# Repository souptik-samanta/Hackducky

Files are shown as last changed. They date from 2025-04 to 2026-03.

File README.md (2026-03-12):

# HackDucky - A penetration testing tool.

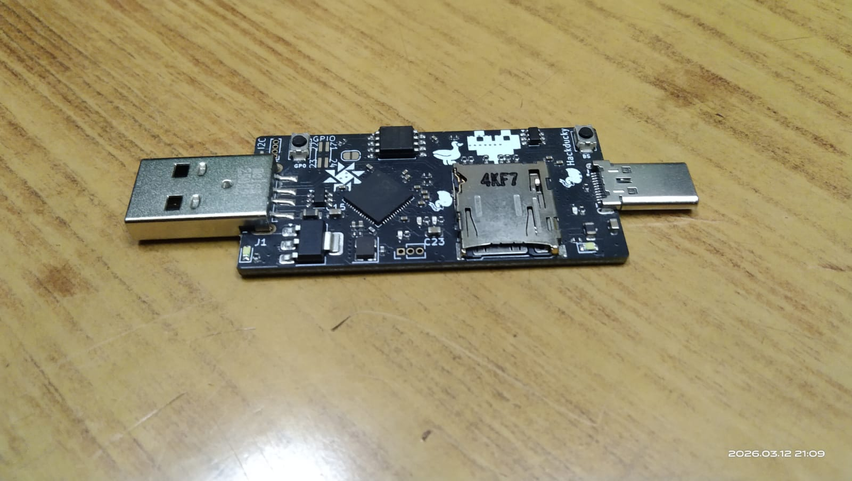
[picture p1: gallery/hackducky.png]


## What is HackDucky
HackDucky is a compact USB automation and security testing device designed in a small portable form factor. It is inspired by keystroke-injection tools and can emulate a USB keyboard to execute scripted commands automatically when plugged into a computer.The device is powered by a rp2040 and supports payload scripting, making it useful for automation, demonstrations, and authorized penetration testing.
Below is the render of the HackDucky board.
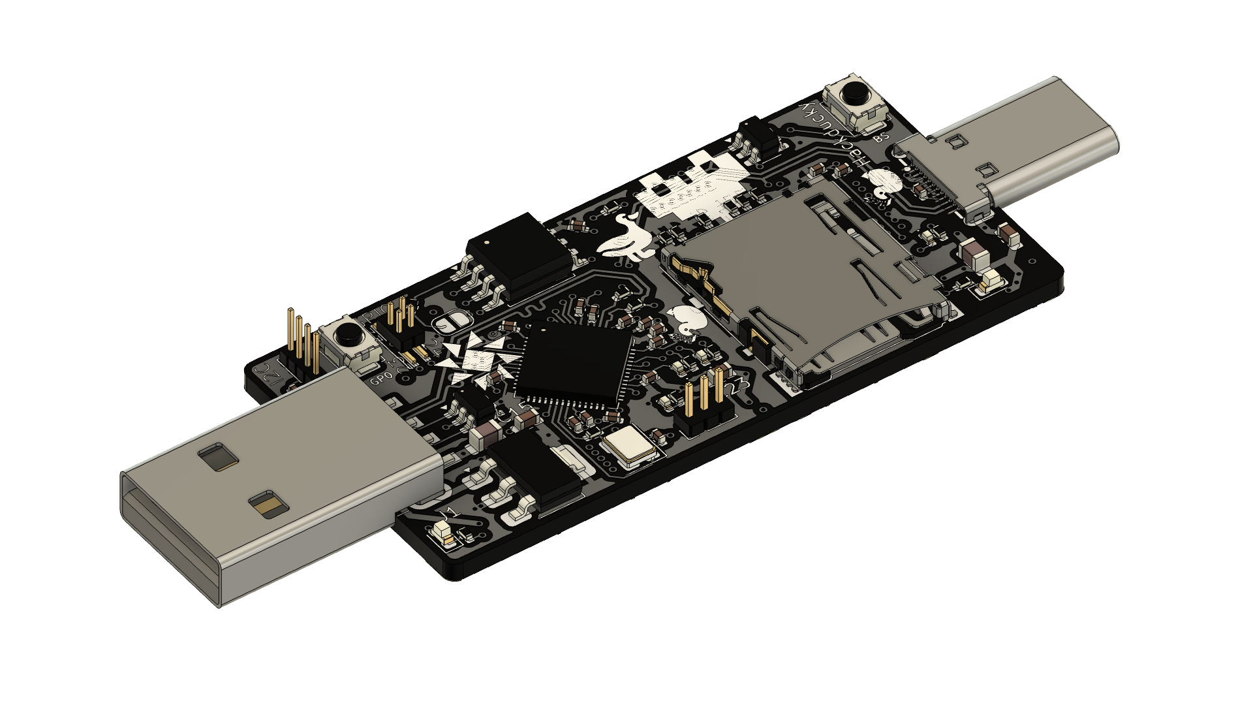
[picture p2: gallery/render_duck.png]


## Why HackDucky
Most devices designed for USB automation or security testing are either expensive, closed-source, or difficult for beginners to modify. We wanted to build something compact, affordable, and easy to experiment with while still being powerful enough for real projects. HackDucky aims to provide a small, portable platform for USB automation, inspired by devices used in security research such as USB Rubber Ducky and other BadUSB-style tools.

Our board is powered by the reliable Raspberry Pi RP2040 microcontroller and includes 16 MB of flash storage, giving plenty of room for scripts and firmware. It also features an SD card slot, allowing users to store and switch between multiple payloads or automation scripts easily. This makes the device flexible for experimentation, demos, and authorized security testing.

HackDucky is designed for a wide range of users. Students can explore how USB HID devices work and learn about hardware security concepts. Makers can use it as a programmable USB automation tool for repetitive tasks. Security enthusiasts can experiment with BadUSB-style techniques in controlled environments, while developers can modify the firmware and hardware to create their own custom tools.

# Features

- RP2040 Microcontroller – Dual-core Arm Cortex-M0+ running at 133 MHz
- 16 MB Flash Storage – Store firmware and large script libraries
- USB-A + USB-C Ports – Flexible connection to different hosts
- MicroSD Card Slot – External storage for payloads and logs
- Led Indicator – Shows device status and script execution
- HID Emulation – Can behave as a keyboard or other USB device
- Script Execution – Run automation scripts automatically
- Open Hardware Design – Fully customizable firmware and PCB
- Compact Portable PCB – Designed for experimentation and hacking

## Getting Started

Your HackDucky ships **without firmware preinstalled**, so you need to flash it before using the board.

### Step 1 — Flash CircuitPython

1. Visit the CircuitPython download page for the RP2040.
2. Download the `.uf2` firmware file.
3. Plug your HackDucky into your computer.
4. A drive named **RPI-RP2** should appear.
5. Drag and drop the `.uf2` file onto the drive.

After flashing, a new drive named **CIRCUITPY** should appear.

---

### Step 2 — Install the Firmware

1. Clone the repository:

```bash
git clone https://github.com/hackclub/hackducky
```
2. Open the repository and navigate to the firmware directory.

3. Copy all files from the firmware folder to the CIRCUITPY drive.

4. Replace existing files if prompted.

5. Delete the existing code.py file.

### Step 3 — Add Your Script

1. Open the ducks folder on the HackDucky drive.

2. Delete any existing files in the folder.

3. Copy your script into the folder with the .ducky extension.

4. Your HackDucky is now ready to run scripts.

```bash
Enjoy ¯\_(ツ)_/¯
```

## Keystroke emulation (wait for video)

<video width="560" height="315" controls>
  <source src="gallery/keystroke.mp4" type="video/mp4">
  Your browser does not support the video tag.
</video>

[Watch on YouTube](https://www.youtube.com/watch?v=__JWsmGk8Tg)

# Team
- @Souptik Samanta
- @Aarav Jham
- @Some1

# Contact
Email Souptik at me@souptik.me(me[at]souptik[dot]me)

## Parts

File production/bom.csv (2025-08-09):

Designator | Footprint | Quantity | Value | LCSC Part #
C1, C10, C9 | 0402 | 3 | 1uF
C11, C17, C18, C19, C20, C21, C22, C24, C25, C7, C8 | 0402 | 11 | 100nF
C12, C13 | 0402 | 2 | 15pF
C14, C15, C23 | 0603 | 3 | 22uF
C16 | 0402 | 1 | 100n
D1, D2, D3, D4 | 0402 | 4 | LED
D5, D6 | 0603 | 2 | LED
FB1, FB2 | 0805 | 2 | 120ohm.100Mhz
J1 | USB_A_CNCTech_1001-011-01101_Horizontal | 1 | USB_A
J2 | PinHeader_2x02_P1.00mm_Vertical_SMD | 1 | Conn_02x02_Top_Bottom
J3 | microSD_HC_Hirose_DM3AT-SF-PEJM5 | 1 | Micro_SD_Card
J4 | PinHeader_1x03_P1.27mm_Vertical | 1 | Conn_01x03_Pin
J6 | PinHeader_1x04_P1.00mm_Vertical | 1 | Conn_01x04_Pin
JP1 | SolderJumper-2_P1.3mm_Open_RoundedPad1.0x1.5mm | 1 | Jumper_2_Open
P2 | USB-C-SMD_U261-121N-4BS2S | 1 | USB_C_Plug
R1, R2 | 0402 | 2 | R
R10, R3, R5, R6 | 0402 | 4 | 220
R15 | 0402 | 1 | DNF
R16, R17, R18, R19, R20, R21 | 0402 | 6 | 10k
R22, R7 | 0402 | 2 | 27.4
R4 | 0402 | 1 | 5.1K
R8, R9 | 0402 | 2 | 1k
SW3 | SW_Push_SPST_NO_Alps_SKRK | 1 | BOOT_SEL | C318884
SW4 | SW_Push_SPST_NO_Alps_SKRK | 1 | GP0 | C318884
TP1, TP10, TP11, TP12, TP2, TP3, TP4, TP5, TP6, TP7, TP8, TP9 | TestPoint_Pad_D1.0mm | 12 | TestPoint
U2 | SOT-223-3_TabPin2 | 1 | AMS1117-3.3
U3 | SOIC-8_5.3x5.3mm_P1.27mm | 1 | W25Q128JVS
U4 | QFN-56-1EP_7x7mm_P0.4mm_EP3.2x3.2mm | 1 | RP2040
U5, U6 | SOT-23-6 | 2 | SRV05-4
Y1 | Crystal_SMD_Abracon_ABM8G-4Pin_3.2x2.5mm | 1 | Crystal_GND24

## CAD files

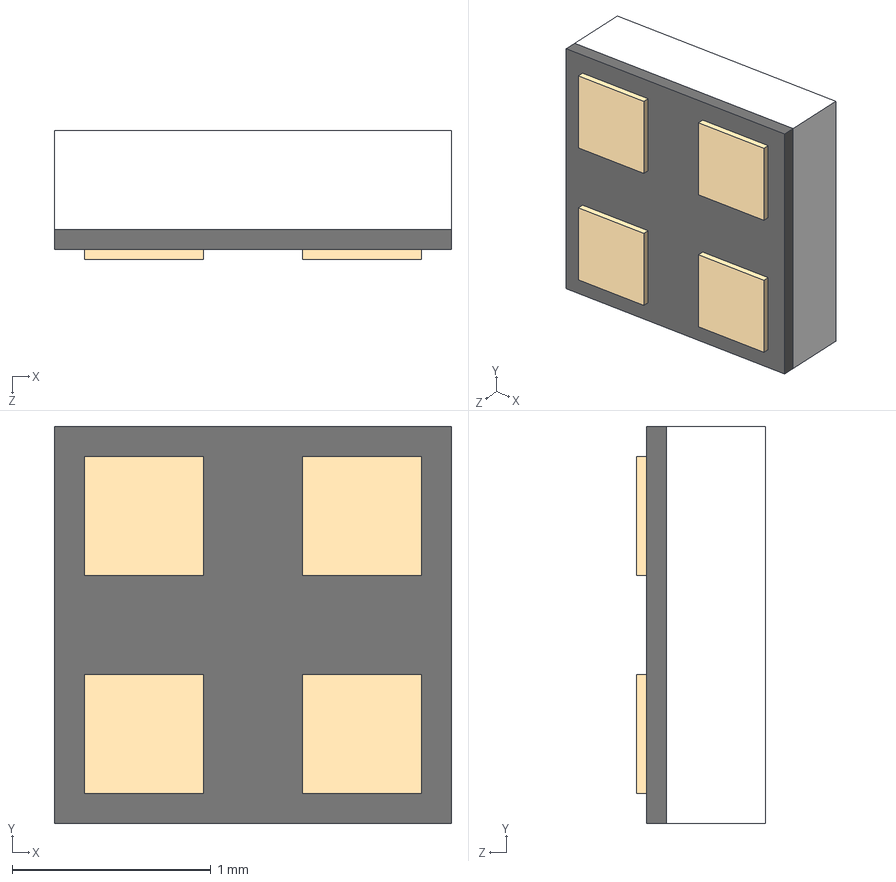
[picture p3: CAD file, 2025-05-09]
3d Model/models/SK6812-EC20.STEP
2.00 x 2.00 x 0.65 mm

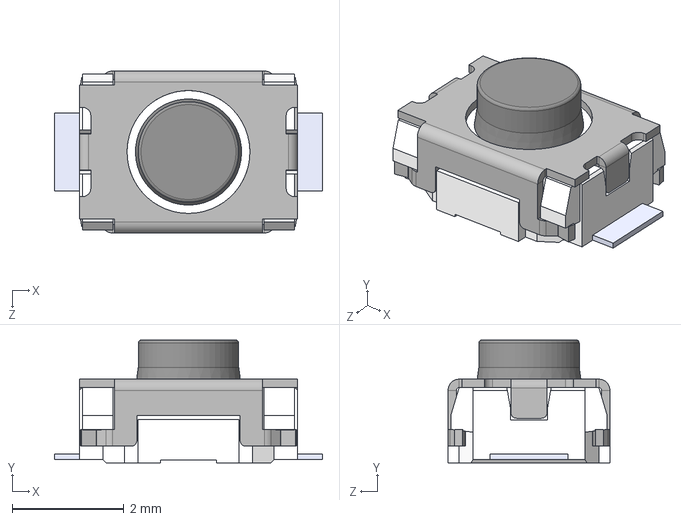
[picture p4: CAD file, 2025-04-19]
3d Model/models/SKRKAHE020--3DModel-STEP-56544.STEP
4.80 x 2.20 x 2.90 mm

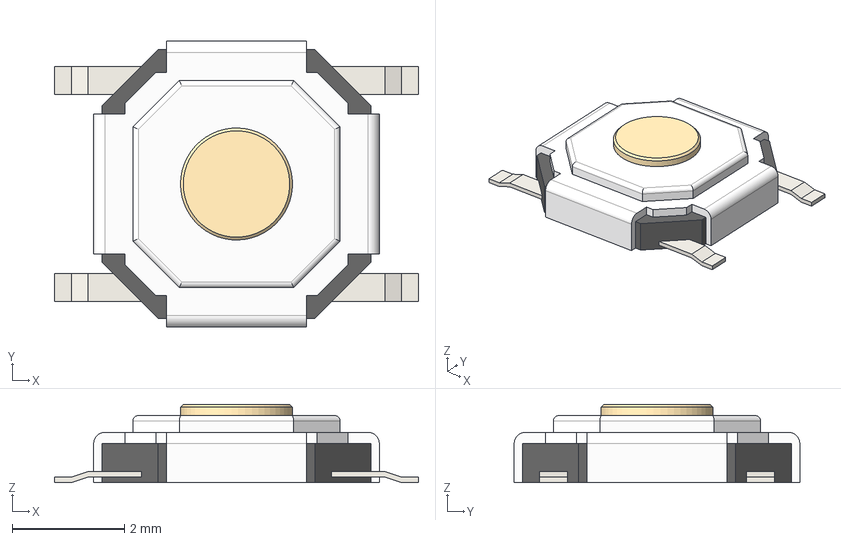
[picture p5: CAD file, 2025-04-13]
3d Model/models/TS-1187A.step
6.50 x 5.10 x 1.40 mm

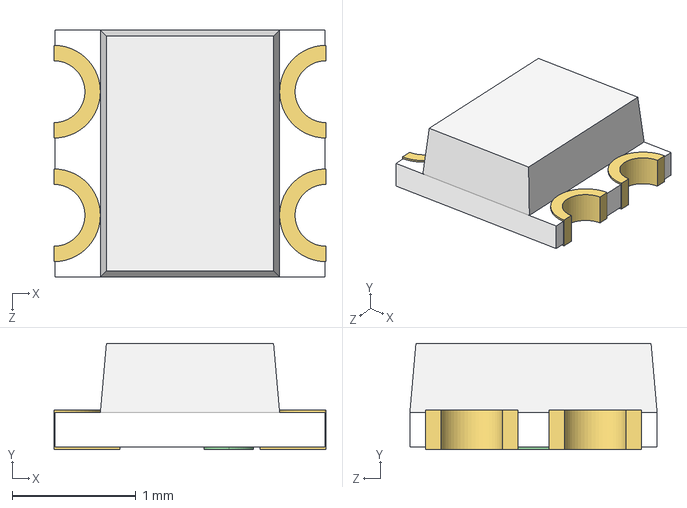
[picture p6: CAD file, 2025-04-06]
3d Model/models/WS2812-2020.STEP
2.20 x 0.86 x 2.00 mm

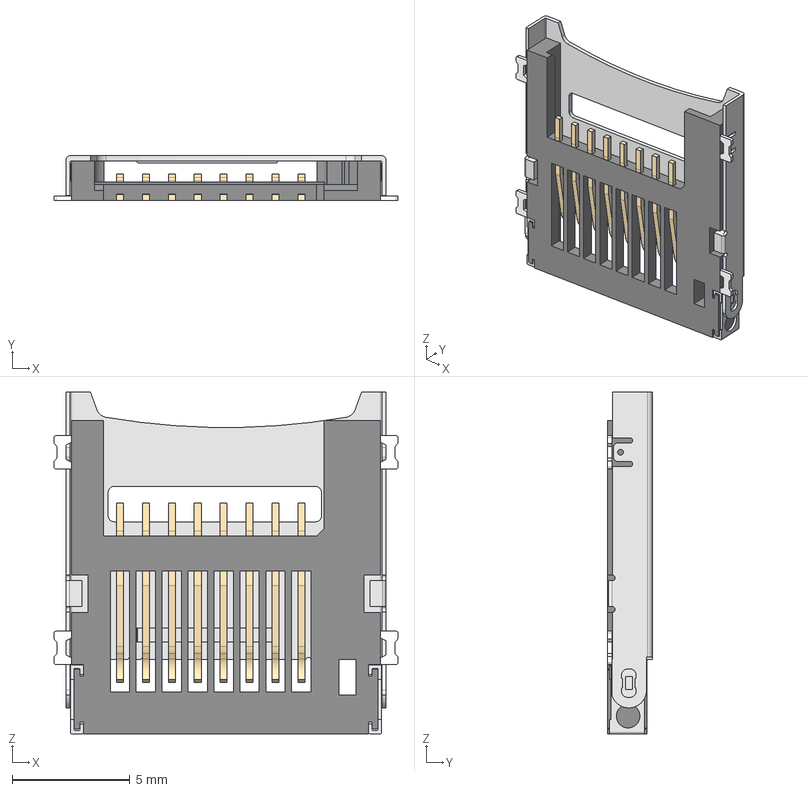
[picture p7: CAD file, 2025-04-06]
3d Model/models/472192001 v1.step
14.6 x 1.90 x 14.5 mm
Pins
Mounting
Cover
Hinge

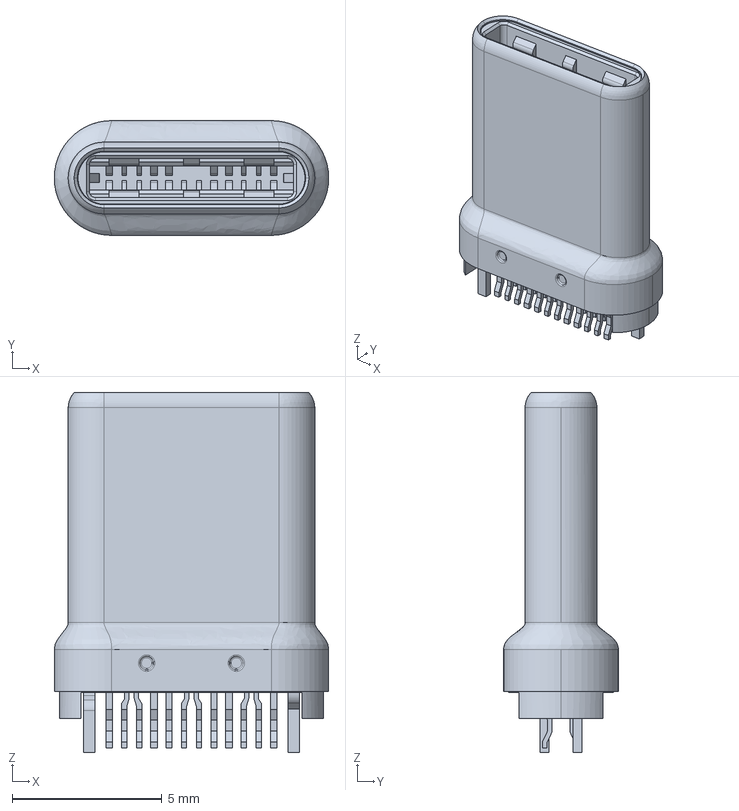
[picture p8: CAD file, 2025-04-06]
3d Model/models/1054440011.stp
9.18 x 3.84 x 12.0 mm

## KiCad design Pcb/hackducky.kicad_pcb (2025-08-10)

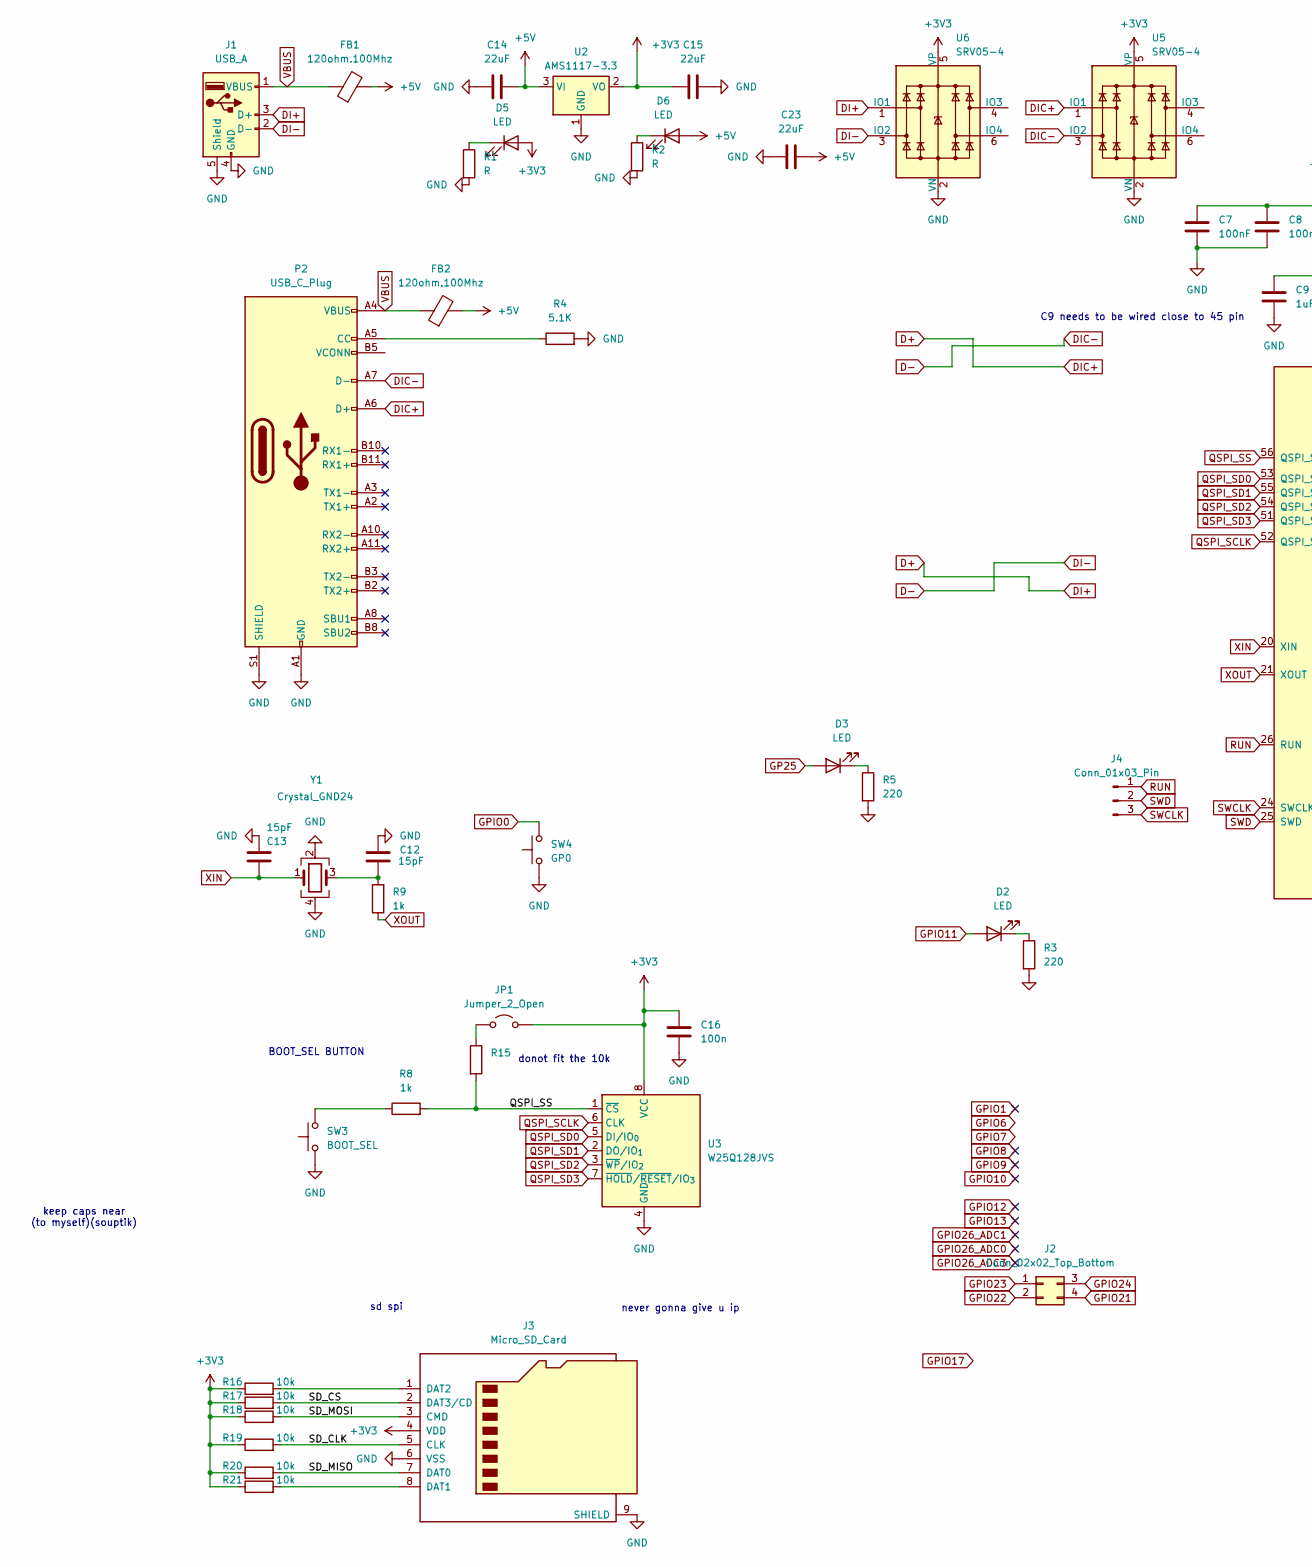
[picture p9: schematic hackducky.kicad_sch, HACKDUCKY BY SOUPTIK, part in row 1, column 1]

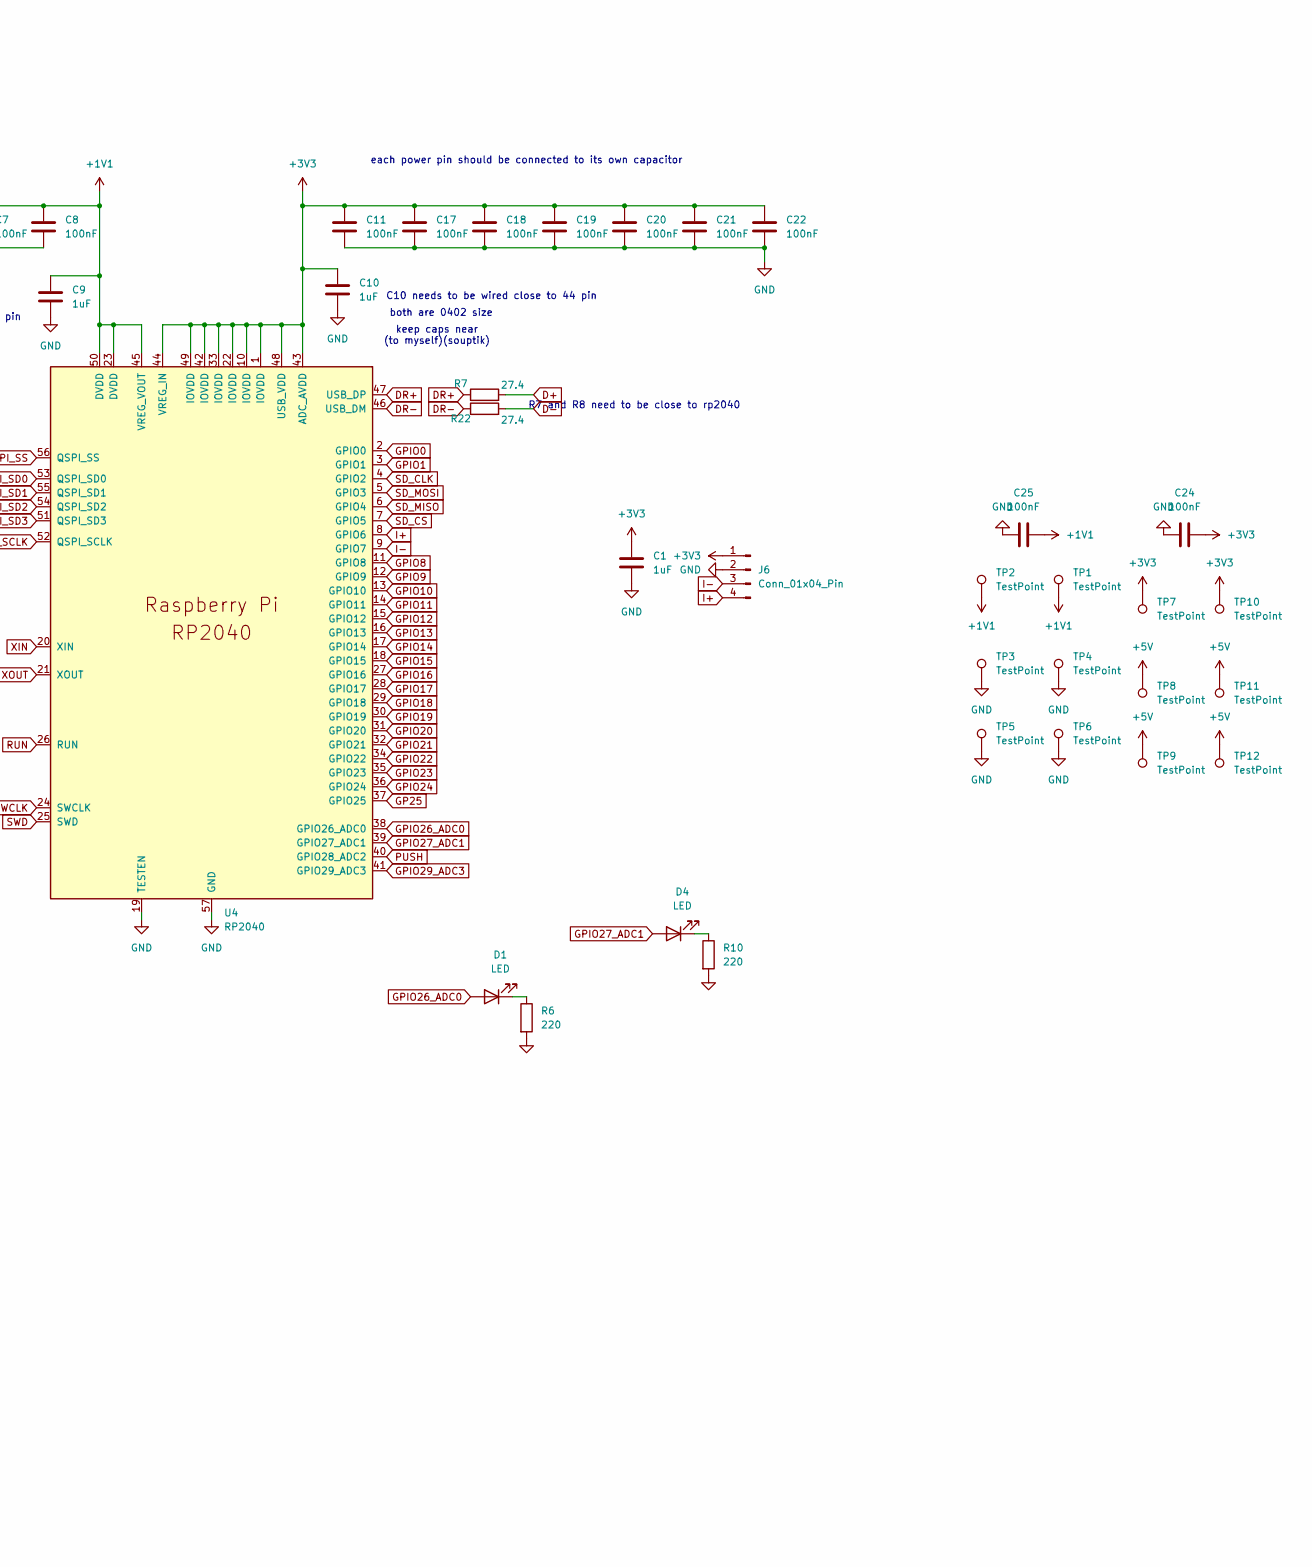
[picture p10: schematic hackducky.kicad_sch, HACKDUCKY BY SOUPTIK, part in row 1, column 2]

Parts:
C1, C9, C10: 1uF; C_0402_1005Metric
C7, C8, C11, C17, C18, C19, C20, C21, C22, C24, C25: 100nF; C_0402_1005Metric
C12, C13: 15pF; C_0402_1005Metric
C14, C15, C23: 22uF; C_0603_1608Metric
C16: 100n; C_0402_1005Metric
D1, D2, D3, D4: LED; LED_0402_1005Metric
D5, D6: LED; LED_0603_1608Metric
FB1, FB2: 120ohm.100Mhz; L_0805_2012Metric
J1: USB_A; USB_A_CNCTech_1001-011-01101_Horizontal
J2: Conn_02x02_Top_Bottom; PinHeader_2x02_P1.00mm_Vertical_SMD
J3: Micro_SD_Card; microSD_HC_Hirose_DM3AT-SF-PEJM5
J4: Conn_01x03_Pin; PinHeader_1x03_P1.27mm_Vertical
J6: Conn_01x04_Pin; PinHeader_1x04_P1.00mm_Vertical
JP1: Jumper_2_Open; SolderJumper-2_P1.3mm_Open_RoundedPad1.0x1.5mm
P2: USB_C_Plug; USB-C-SMD_U261-121N-4BS2S
R1, R2: R; R_0402_1005Metric
R3, R5, R6, R10: 220; R_0402_1005Metric
R4: 5.1K; C_0402_1005Metric
R7, R22: 27.4; R_0402_1005Metric
R8, R9: 1k; R_0402_1005Metric
R15: DNF; R_0402_1005Metric
R16, R17, R18, R19, R20, R21: 10k; R_0402_1005Metric
SW3: BOOT_SEL; SW_Push_SPST_NO_Alps_SKRK; LCSC C318884
SW4: GP0; SW_Push_SPST_NO_Alps_SKRK; LCSC C318884
TP1, TP2, TP3, TP4, TP5, TP6, TP7, TP8, TP9, TP10, TP11, TP12: TestPoint; TestPoint_Pad_D1.0mm
U2: AMS1117-3.3; SOT-223-3_TabPin2
U3: W25Q128JVS; SOIC-8_5.3x5.3mm_P1.27mm
U4: RP2040; QFN-56-1EP_7x7mm_P0.4mm_EP3.2x3.2mm
U5, U6: SRV05-4; SOT-23-6
Y1: Crystal_GND24; Crystal_SMD_Abracon_ABM8G-4Pin_3.2x2.5mm

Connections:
+1V1: C7.1, C8.1, C9.1, C25.2, TP1.1, TP2.1, U4.23 (DVDD), U4.45 (VREG_VOUT), U4.50 (DVDD)
+3V3: C1.1, C10.1, C11.1, C15.2, C16.1, C17.1, C18.1, C19.1, C20.1, C21.1, C22.1, C24.2, D5.2 (A), J3.4 (VDD), J6.1, JP1.2 (B), R16.1, R17.1, R18.1, R19.1, R20.1, R21.1, TP7.1, TP10.1, U2.2 (VO), U3.8 (VCC), U4.1 (IOVDD), U4.10 (IOVDD), U4.22 (IOVDD), U4.33 (IOVDD), U4.42 (IOVDD), U4.43 (ADC_AVDD), U4.44 (VREG_IN), U4.48 (USB_VDD), U4.49 (IOVDD), U5.5 (VP), U6.5 (VP)
+5V: C14.1, C23.1, D6.2 (A), FB1.2, FB2.2, TP8.1, TP9.1, TP11.1, TP12.1, U2.3 (VI)
D+: J1.3 (D+), P2.A6 (D+), R7.2, U5.1 (IO1), U6.1 (IO1)
D-: J1.2 (D-), P2.A7 (D-), R22.2, U5.3 (IO2), U6.3 (IO2)
DR+: R7.1, U4.47 (USB_DP)
DR-: R22.1, U4.46 (USB_DM)
GND: C1.2, C7.2, C8.2, C9.2, C10.2, C11.2, C12.2, C13.2, C14.2, C15.1, C16.2, C17.2, C18.2, C19.2, C20.2, C21.2, C22.2, C23.2, C24.1, C25.1, J1.4 (GND), J1.5 (Shield), J3.6 (VSS), J3.9 (SHIELD), J6.2, P2.A1 (GND), P2.A12 (GND), P2.B1 (GND), P2.B12 (GND), P2.S1 (SHIELD), R1.2, R2.2, R3.2, R4.2, R5.2, R6.2, R10.2, SW3.1, SW4.1, TP3.1, TP4.1, TP5.1, TP6.1, U2.1 (GND), U3.4 (GND), U4.19 (TESTEN), U4.57 (GND), U5.2 (VN), U6.2 (VN), Y1.2, Y1.4
GP25: D3.2 (A), U4.37 (GPIO25)
GPIO0: SW4.2, U4.2 (GPIO0)
GPIO1: U4.3 (GPIO1)
GPIO8: U4.11 (GPIO8)
GPIO9: U4.12 (GPIO9)
GPIO10: U4.13 (GPIO10)
GPIO11: D2.2 (A), U4.14 (GPIO11)
GPIO12: U4.15 (GPIO12)
GPIO13: U4.16 (GPIO13)
GPIO14: U4.17 (GPIO14)
GPIO15: U4.18 (GPIO15)
GPIO16: U4.27 (GPIO16)
GPIO17: U4.28 (GPIO17)
GPIO18: U4.29 (GPIO18)
GPIO19: U4.30 (GPIO19)
GPIO20: U4.31 (GPIO20)
GPIO21: J2.4, U4.32 (GPIO21)
GPIO22: J2.2, U4.34 (GPIO22)
GPIO23: J2.1, U4.35 (GPIO23)
GPIO24: J2.3, U4.36 (GPIO24)
GPIO26_ADC0: D1.2 (A), U4.38 (GPIO26_ADC0)
GPIO27_ADC1: D4.2 (A), U4.39 (GPIO27_ADC1)
GPIO29_ADC3: U4.41 (GPIO29_ADC3)
I+: J6.4, U4.8 (GPIO6)
I-: J6.3, U4.9 (GPIO7)
unnamed: C12.1, R9.2, Y1.3
unnamed: D1.1 (K), R6.1
unnamed: D2.1 (K), R3.1
unnamed: D3.1 (K), R5.1
unnamed: D4.1 (K), R10.1
unnamed: D5.1 (K), R1.1
unnamed: D6.1 (K), R2.1
unnamed: J3.8 (DAT1), R21.2
unnamed: J3.1 (DAT2), R16.2
unnamed: JP1.1 (A), R15.1
unnamed: P2.A5 (CC), R4.1
unnamed: R8.1, SW3.2
PUSH: U4.40 (GPIO28_ADC2)
QSPI_SCLK: U3.6 (CLK), U4.52 (QSPI_SCLK)
QSPI_SD0: U3.5 (DI/IO_{0}), U4.53 (QSPI_SD0)
QSPI_SD1: U3.2 (DO/IO_{1}), U4.55 (QSPI_SD1)
QSPI_SD2: U3.3 (~WP/IO_{2}), U4.54 (QSPI_SD2)
QSPI_SD3: U3.7 (~HOLD/~RESET/IO_{3}), U4.51 (QSPI_SD3)
QSPI_SS: R8.2, R15.2, U3.1 (~CS), U4.56 (QSPI_SS)
RUN: J4.1, U4.26 (RUN)
SD_CLK: J3.5 (CLK), R19.2, U4.4 (GPIO2)
SD_CS: J3.2 (DAT3/CD), R17.2, U4.7 (GPIO5)
SD_MISO: J3.7 (DAT0), R20.2, U4.6 (GPIO4)
SD_MOSI: J3.3 (CMD), R18.2, U4.5 (GPIO3)
SWCLK: J4.3, U4.24 (SWCLK)
SWD: J4.2, U4.25 (SWD)
VBUS: FB1.1, FB2.1, J1.1 (VBUS), P2.A4 (VBUS), P2.A9 (VBUS), P2.B4 (VBUS), P2.B9 (VBUS)
XIN: C13.1, U4.20 (XIN), Y1.1
XOUT: R9.1, U4.21 (XOUT)

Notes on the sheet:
sd spi
C9 needs to be wired close to 45 pin
keep caps near (to myself)(souptik)
donot fit the 10k
R7 and R8 need to be close to rp2040
C10 needs to be wired close to 44 pin
BOOT_SEL BUTTON
never gonna give u ip
both are 0402 size
each power pin should be connected to its own capacitor

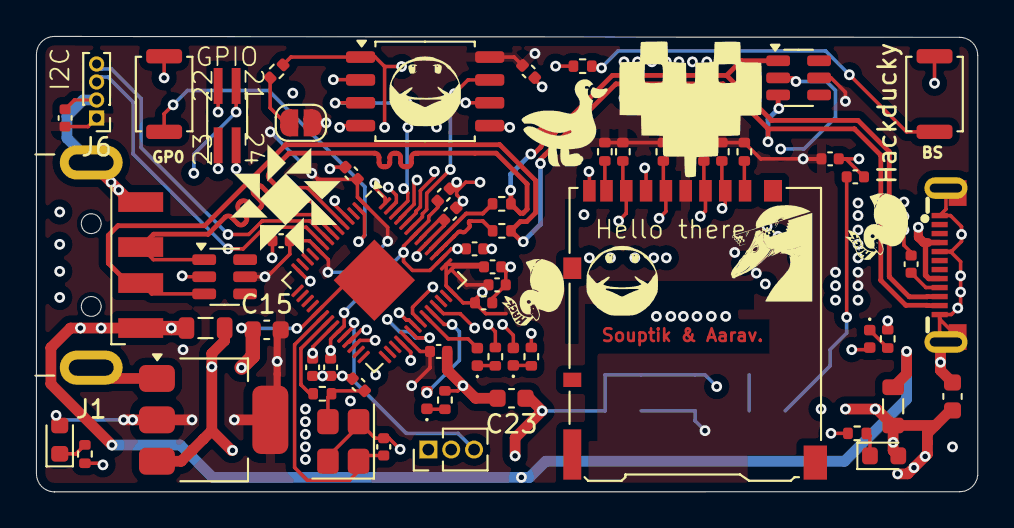
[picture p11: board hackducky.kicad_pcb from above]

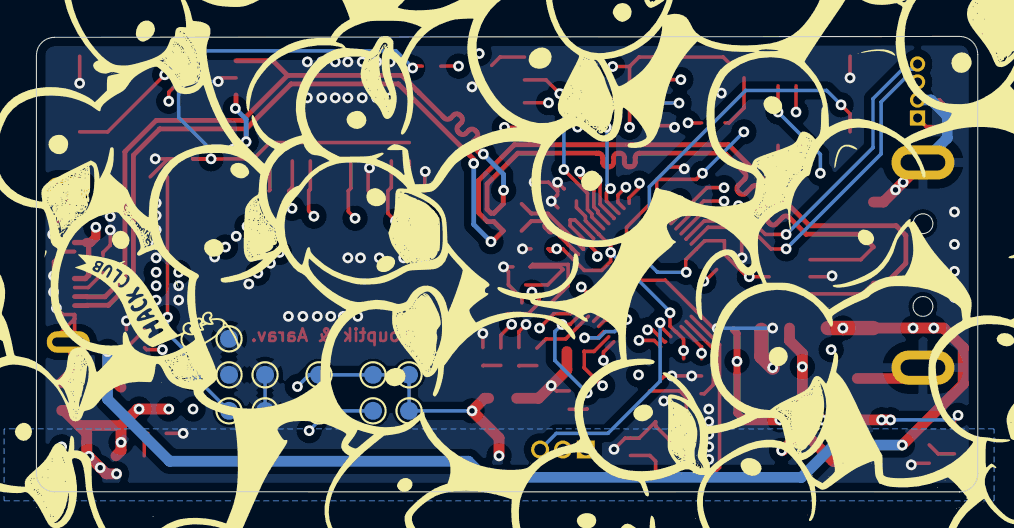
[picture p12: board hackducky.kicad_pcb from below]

Board: 4 copper layers, 52.3 x 25.3 mm, 73 parts (12 on the bottom side), 47 nets.

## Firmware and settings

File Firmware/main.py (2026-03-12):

# NOT IMPLEMENTED: BUTTON, ATTACKMODE, LED, $_RANDOM_MIN, $_RANDOM_MAX

import digitalio
import board

print("Main.py: Starting up...")
# Setup LED
status_led = digitalio.DigitalInOut(board.LED)
status_led.direction = digitalio.Direction.OUTPUT


def flash_error():
    while True:
        status_led.value = True
        time.sleep(0.1)
        status_led.value = False
        time.sleep(0.1)


import adafruit_logging as logging
from adafruit_logging import FileHandler

logger = logging.getLogger("compiler.py")
logger.setLevel(logging.DEBUG)
programming_mode = True

try:
    LOG_FILE_PATH = "/debug.log"
    filehandler = FileHandler(LOG_FILE_PATH)
    logger.addHandler(filehandler)
    import adafruit_datetime as datetime

    logger.info(f"BOOT {datetime.datetime.now()}")
    programming_mode = False
except:
    print("Debug mode active...")
    print("Logging to file is disabled.")


try:
    import time
    import usb_hid
    import os
    import random as rand
    from random_keystrokes import RANDOM_KEYSTROKES

    MODIFIER_KEYS = ["CTRL", "SHIFT", "ALT", "GUI", "WINDOWS", "COMMAND", "CONTROL"]

    SPECIAL_KEYS = [
        "ENTER",
        "DELETE",
        "ESCAPE",
        "UP_ARROW",
        "DOWN_ARROW",
        "LEFT_ARROW",
        "RIGHT_ARROW",
        "BACKSPACE",
        "SPACE",
        "TAB",
        "MENU",
        "APPLICATION",
        "PRINT_SCREEN",
        "PAUSE",
        "INSERT",
        "DELETE",
        "PAGE_DOWN",
        "PAGE_UP",
        "HOME",
        "END",
        "F1",
        "F2",
        "F3",
        "F4",
        "F5",
        "F6",
        "F7",
        "F8",
        "F9",
        "F10",
        "F11",
        "F12",
        "CAPS_LOCK",
        "NUML_OCK",
        "SCROLL_LOCK",
    ]

    class DuckyScriptError(Exception):
        pass

    # For programming mode
    # ================================================================
    class PseudoKeyboard:
        def press(self, a):
            pass

        def release_all(self):
            pass

    class PseudoLayout:
        def write(self, a):
            pass

    class PseudoKeycode:
        pass

    if programming_mode:

        def getattr(o, s):
            return s

    # ================================================================

    class DuckyScriptCompiler:
        def __init__(self, layout, keyboard, keycode) -> None:
            self.layout = layout
            self.keyboard = keyboard
            self.keycode = keycode
            self.default_delay = 20
            self.var_table: dict[str, int | bool] = {}
            self.const_table: dict[str, int | str] = {}
            self.if_condition_stack: list[bool] = []
            self.function_table: dict[str, list] = {}
            self.call_stack: list = []  # Track function calls for return values
            self.return_value: int | bool | None = (
                None  # Store the most recent return value
            )
            self.var_table["$_RANDOM_MIN"] = 0
            self.var_table["$_RANDOM_MAX"] = 9

            # If debug mode is active, then we should still send debug messages but not do anything.
            if programming_mode:
                self.layout = PseudoLayout()
                self.keyboard = PseudoKeyboard()
                self.keycode = PseudoKeycode()

        def sanitise(self, lines: list[str]) -> list[str]:
            """Sanitises raw duckyscript to remove comments and whitespace."""
            sanitised: list[str] = []

            iterator = iter(lines)
            for line in iterator:
                line = line.strip()

                if not line:
                    continue

                if line.startswith("REM_BLOCK"):
                    try:
                        while not next(iterator).startswith("END_REM"):
                            pass
                    except StopIteration:
                        raise DuckyScriptError(
                            "A REM_BLOCK was started but no END_REM was found."
                        )

                if line.startswith("REM"):
                    continue

                sanitised.append(line)

            return sanitised

        def compile(self, lines: list[str]) -> list:
            """Accepts duckyscript, then builds a list of functions to call in order."""
            # First pass: sanitise
            lines = self.sanitise(lines)
            # logger.debug(f"{lines}")
            # Second pass: generate constants table
            lines = self.generate_constants(lines)
            # logger.debug(f"{lines}")
            # Third pass: replace the constants
            lines = self.replace_constants(lines)
            # logger.debug(f"{lines}")
            lines = self.replace_random(lines)
            # logger.debug(f"{lines}")

            compiled_funcs = self._compile_block(lines)

            if self.if_condition_stack:
                raise DuckyScriptError(
                    "Reached end of file with unclosed IF statement(s)."
                )

            return compiled_funcs

        def _compile_block(self, lines: list[str]) -> list:
            out: list = []

            iterator = iter(lines)
            row = 0  # Track the row for reporting errs.
            for line in iterator:
                row += 1
                line = line.split()
                command = line[0]

                if command == "FUNCTION":
                    func_name = line[1] if len(line) > 1 else ""

                    # Validate function name
                    if not func_name.endswith("()") or not self._is_valid_function_name(
                        func_name
                    ):
                        raise DuckyScriptError(f"Invalid function name: {func_name}")

                    # Extract function body
                    func_body_lines = []
                    nesting_level = 1
                    for func_line in iterator:
                        stripped_line = func_line.strip()
                        if stripped_line.startswith("FUNCTION"):
                            nesting_level += 1
                        elif stripped_line == "END_FUNCTION":
                            nesting_level -= 1

                        if nesting_level == 0:
                            break

                        func_body_lines.append(func_line)
                    else:
                        raise DuckyScriptError(
                            f"FUNCTION {func_name} was not closed with END_FUNCTION."
                        )

                    # Store the function definition
                    self.function_table[func_name] = func_body_lines
                    logger.debug(f"Defined function: {func_name}")
                    continue

                # Handle function calls
                elif command.endswith("()") and command in self.function_table:
                    func_name = command
                    out.append(lambda fn=func_name: self._execute_function(fn))
                    continue

                # Handle RETURN statement
                elif command == "RETURN":
                    if len(line) > 1:
                        # Evaluate return expression
                        return_tokens = line[1:]
                        return_value = self.evaluate_expression(return_tokens)
                        out.append(lambda rv=return_value: self._do_return(rv))
                    else:
                        out.append(lambda: self._do_return(None))
                    continue

                if command == "WHILE":
                    # We are already inside a block that should be executed, so we compile the loop.
                    condition_tokens = line[1:]

                    # Gather all lines that form the body of the loop
                    loop_body_lines = []
                    nesting_level = 1
                    for loop_line in iterator:
                        if loop_line.strip().startswith("WHILE"):
                            nesting_level += 1
                        elif loop_line.strip() == "END_WHILE":
                            nesting_level -= 1

                        if nesting_level == 0:
                            break  # We found the matching END_WHILE

                        loop_body_lines.append(loop_line)
                    else:
                        # If not broken out of
                        raise DuckyScriptError(
                            "WHILE statement was not closed with END_WHILE."
                        )

                    compiled_loop_body = self._compile_block(loop_body_lines)

                    # Create a single function that runs the entire loop
                    loop_func = (
                        lambda ct=condition_tokens,
                        body=compiled_loop_body: self._execute_while_loop(ct, body)
                    )
                    out.append(loop_func)
                    continue

                # Check if blocks
                if command == "IF":
                    condition_result = self._evaluate_condition(line[1:])
                    self.if_condition_stack.append(condition_result)
                    logger.debug(
                        f"IF condition '{' '.join(line[1:])}' evaluated to {condition_result}. Stack: {self.if_condition_stack}"
                    )
                    continue

                elif command == "ELSE":
                    if not self.if_condition_stack:
                        raise DuckyScriptError(
                            f"ELSE found without a preceding IF at line {row}"
                        )
                    # Invert the condition for the current block
                    self.if_condition_stack[-1] = not self.if_condition_stack[-1]
                    logger.debug(
                        f"ELSE found. Inverting condition. Stack: {self.if_condition_stack}"
                    )
                    continue

                elif command == "END_IF":
                    if not self.if_condition_stack:
                        raise DuckyScriptError(
                            f"END_IF found without a preceding IF at line {row}"
                        )
                    _ = self.if_condition_stack.pop()
                    logger.debug(
                        f"END_IF found. Popped from stack. Stack: {self.if_condition_stack}"
                    )
                    continue

                should_execute = all(self.if_condition_stack)
                if not should_execute:
                    logger.debug(f"Skipping line {row} due to false condition.")
                    continue

                # Normal keyword / commands idk
                if command == "STRING":
                    logger.debug(f"Processing STRING statement at row {row} , {line}")
                    if len(line) >= 2:
                        s = " ".join(line[1:])
                        out.append(lambda s=s: self.string(s))
                    else:
                        logger.debug("STRING block found,")
                        string: list[str] = []
                        n = next(iterator)
                        while n != "END_STRING":
                            string.append(n)
                            n = next(iterator)
                        s = "".join(string)
                        logger.debug(f"END STRING block with value {s}")
                        out.append(lambda s=s: self.string(s))

                if command == "STRINGLN":
                    logger.debug(f"Processing STRINGLN statement at row {row} , {line}")
                    if len(line) >= 2:
                        s = " ".join(line[1:])
                        out.append(lambda s=s: self.stringln(s))
                    else:
                        logger.debug("STRINGLN block found,")
                        string: list[str] = []
                        n = next(iterator)
                        while n != "END_STRINGLN":
                            out.append(lambda s=n: self.stringln(s))
                            n = next(iterator)
                        logger.debug("END STRINGLN block with value")

                elif command == "DELAY":
                    if len(line) > 1:
                        try:
                            val = self.get_value(line[1])
                            if type(val) != int:
                                raise DuckyScriptError(f"Invalid integer {val}")
                            out.append(lambda t=val: self.delay(t))
                        except ValueError:
                            raise DuckyScriptError(
                                f"Invalid integer found at line {row}"
                            )
                    else:
                        out.append(lambda t=self.default_delay: self.delay(t))

                elif command in MODIFIER_KEYS or command in SPECIAL_KEYS:
                    keys = line
                    out.append(lambda k=keys: self.do_key(k))

                elif command == "INJECT_MOD":
                    key = line[1]
                    out.append(lambda k=key: self.do_key(k))

                elif command == "DEFAULT_DELAY":
                    try:
                        val = self.get_value(line[1])
                        if type(val) != int:
                            raise DuckyScriptError(f"Invalid integer {val}")
                        out.append(lambda t=val: self.default_delay)
                    except IndexError as e:
                        raise DuckyScriptError(e)

                elif command == "VAR":
                    logger.debug(f"Processing VAR statement, {line}")
                    try:
                        var_name, value_str = line[1], line[3]
                        var_name = var_name.strip()
                        if not var_name.startswith("$"):
                            raise DuckyScriptError(
                                f"Invalid variable name: '{var_name}'"
                            )
                        elif var_name in self.var_table:
                            raise DuckyScriptError(
                                f"Attempted to redefine existing variable '{var_name}'"
                            )

                        value_tokens = value_str.strip().split()
                        self.var_table[var_name] = self.evaluate_expression(
                            value_tokens
                        )
                        logger.debug(
                            f"Defined variable {var_name} = {self.var_table[var_name]}"
                        )
                    except ValueError:
                        raise DuckyScriptError(f"Invalid VAR syntax: {line}")

                elif command.startswith("$"):
                    out.append(lambda l=line: self.reassign(l))

            return out

        def generate_constants(self, lines: list[str]) -> list[str]:
            # Use this on pass 1
            """
            Process DuckyScript to add constants.

            :param list[str] lines: sanitised duckyscript source
            :return: duckyscript with constant definitions removed
            :rtype: list[str]
            """
            out: list[str] = []
            row = 0
            for line in lines:
                row += 1
                line = line.split()
                if line[0] == "DEFINE":
                    logger.debug("DEFINE statement found.")
                    if len(line) < 3:
                        raise DuckyScriptError(
                            f"Error while trying to define a constant in line {row}: {' '.join(line)}"
                        )
                    try:
                        self.const_table[line[1]] = int(" ".join(line[2:]))
                        logger.debug(f"Added {line[1]} to constant table as int.")
                    except:
                        self.const_table[line[1]] = " ".join(line[2:])
                        logger.debug(f"Added {line[1]} to constant table as str.")
                else:
                    out.append(" ".join(line))
            return out

        def replace_constants(self, lines: list[str]) -> list[str]:
            """Replaces all constant names with their value"""
            out: list[str] = []
            row = 0
            for line in lines:
                row += 1
                line = line.split()
                for i in range(len(line)):
                    if self.const_table.get(line[i]):
                        logger.debug(
                            f"Replaced {line[i]} with {self.const_table[line[i]]} at row {row}"
                        )
                        line[i] = str(self.const_table[line[i]])
                out.append(" ".join(line))
            return out

        def replace_random(self, lines: list[str]) -> list[str]:
            out: list[str] = []
            row = 0
            for line in lines:
                row += 1
                line = line.split()
                for i in range(len(line)):
                    if line[i] in RANDOM_KEYSTROKES:
                        random = RANDOM_KEYSTROKES[line[i]]()
                        logger.debug(f"Replaced {line[i]} with {random} at row {row}")
                        line[i] = random
                out.append(" ".join(line))
            return out

        def get_value(self, token: str) -> int | bool | None:
            """Resolves a token into its value, handling function calls."""
            token = token.strip()

            # Check for function call first
            if token.endswith("()") and token in self.function_table:
                return self.evaluate_function_call(token)

            # Then check for variables
            if token.startswith("$") and token in self.var_table:
                return self.var_table[token]
            elif token == "$_RANDOM_INT":
                print(self.var_table["$_RANDOM_MIN"], self.var_table["$_RANDOM_MAX"])
                return rand.randint(
                    self.var_table["$_RANDOM_MIN"], self.var_table["$_RANDOM_MAX"]
                )

            # Then check for literals
            if token.upper() == "TRUE":
                return True
            if token.upper() == "FALSE":
                return False
            if token.upper() == "NONE":
                return None

            try:
                return int(token)
            except ValueError:
                raise DuckyScriptError(
                    f"Invalid value: {token}. Must be variable, function call, or literal (int/bool)."
                )

        def evaluate_expression(self, tokens: list[str]) -> int | bool | None:
            """Evaluates expressions, including function calls."""

            if len(tokens) == 1:
                token = tokens[0]
                # Check if it's a function call
                if token.endswith("()") and token in self.function_table:
                    return self.evaluate_function_call(token)
                else:
                    return self.get_value(token)

            left_val = self.evaluate_expression([tokens[0]])
            op = tokens[1]
            right_val = self.evaluate_expression([tokens[2]])

            if isinstance(left_val, (int, bool)) and isinstance(right_val, (int, bool)):
                if op == "+":
                    return left_val + right_val
                elif op == "-":
                    return left_val - right_val
                elif op == "*":
                    return left_val * right_val
                elif op == "/":
                    return left_val // right_val
                elif op == "==":
                    return left_val == right_val
                elif op == "!=":
                    return left_val != right_val
                elif op == ">":
                    return left_val > right_val
                elif op == "<":
                    return left_val < right_val
                elif op == ">=":
                    return left_val >= right_val
                elif op == "<=":
                    return left_val <= right_val

            raise DuckyScriptError(f"Invalid operation: {left_val} {op} {right_val}")

        def _evaluate_condition(self, tokens: list[str]) -> bool:
            """Evaluates conditional expressions, including function calls."""
            result = self.evaluate_expression(tokens)
            if isinstance(result, bool):
                return result
            raise DuckyScriptError(f"Condition must evaluate to boolean, got: {result}")

        def evaluate_function_call(self, func_name: str) -> int | bool | None:
            """Evaluate a function call as part of an expression."""
            self._execute_function(func_name)
            return self.return_value

        def _execute_while_loop(
            self, condition_tokens: list[str], loop_functions: list
        ):
            """
            At runtime, repeatedly evaluates the condition and executes the loop body.
            """
            logger.debug(
                f"Executing WHILE loop with condition: {' '.join(condition_tokens)}"
            )
            # Safety break to prevent accidental infinite loops during testing/dev
            max_iterations = 1000
            iterations = 0

            while self._evaluate_condition(condition_tokens):
                if iterations >= max_iterations:
                    logger.error(
                        "WHILE loop exceeded max iterations. Breaking to prevent freeze."
                    )
                    break

                for func in loop_functions:
                    func()  # Execute one full cycle of the loop body
                iterations += 1
            logger.debug("WHILE loop finished.")

        def _is_valid_function_name(self, name: str) -> bool:
            """Validate function name."""
            if not name.endswith("()"):
                return False
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

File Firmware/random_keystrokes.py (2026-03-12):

import random

LOWERCASE_LETTERS = "abcdefghijklmnopqrstuvwxyz"
UPPERCASE_LETTERS =	"ABCDEFGHIJKLMNOPQRSTUVWXYZ"
LETTERS = "abcdefghijklmnopqrstuvwxyzABCDEFGHIJKLMNOPQRSTUVWXYZ"
NUMBERS =	"0123456789"
SPECIALS =	"!@#$%^&*()"
CHARS = "abcdefghijklmnopqrstuvwxyzABCDEFGHIJKLMNOPQRSTUVWXYZ0123456789!@#$%^&*()"

def random_lower():
    return random.choice(LOWERCASE_LETTERS)

def random_upper():
    return random.choice(UPPERCASE_LETTERS)

def random_letter():
    return random.choice(LETTERS)

def random_number():
    return random.choice(NUMBERS)


def random_special():
    return random.choice(SPECIALS)


def random_char():
    return random.choice(CHARS)

RANDOM_KEYSTROKES = {
        "RANDOM_LOWERCASE_LETTER": random_lower,
        "RANDOM_UPPERCASE_LETTER": random_upper,
        "RANDOM_LETTER": random_letter,
        "RANDOM_NUMBER": random_number,
        "RANDOM_SPECIAL": random_special,
        "RANDOM_CHAR": random_char,
}

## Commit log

2025-04-06 Initial commit of KiCad project
    [1054440011.stp, 472192001 v1.step, WS2812-2020.STEP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]
2025-04-07 sch done
    [hackducky.kicad_sch]
2025-04-07 schm done fl
    [hackducky.kicad_sch]
2025-04-08 schm full done
    [hackducky.kicad_sch]
2025-04-08 pcb layout
    [hackducky.kicad_pcb]
2025-04-13 pcb some few little
    [hackducky.kicad_pcb]
2025-04-13 did pcb a lil bit
    [TS-1187A.step, hackducky.kicad_pcb, hackducky.kicad_sch]
2025-04-17 pcb work
    [hackducky.kicad_pcb]
2025-04-18 did pcb most of work done wooo
    [hackducky.kicad_pcb, hackducky.kicad_sch]
2025-04-18 lets end stream here eh done with qspi and sd so yea https://youtu.be/rrAUqN_xz0k
    [hackducky.kicad_pcb]
2025-04-19 full done yayayay
    [hackducky.kicad_pcb, hackducky.kicad_sch]
2025-04-19 done beter
    [hackducky.kicad_pcb]
2025-04-20 bom fix
    [bom.csv]
2025-04-20 will do pr latr
    [hackducky.kicad_pcb, positions.csv]
2025-04-20 fixed silkscreen
    [hackducky.kicad_pcb]
2025-05-09 v4 mostly tuned paths
    [bom.csv, designators.csv, hackducky.kicad_pcb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]
2025-05-09 add sk6812 model
    [SK6812-EC20.STEP, hackducky.kicad_pcb]
2025-05-13 v4 done
    [hackducky.kicad_pcb]
2025-05-13 added readme and photos:
    [hackducky.kicad_pcb, hackducky.kicad_sch]
2025-05-13 finish finally hell yeah(mostly :pf:)
    [bom.csv, designators.csv, hackducky.kicad_pcb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]
2025-05-14 new sm fic
    [bom.csv, hackducky.kicad_pcb]
2025-05-14 fixed silkscren
    [bom.csv, hackducky.kicad_pcb, positions.csv]
2025-05-18 with bom corrected
    [bom.csv, hackducky.kicad_pcb]
2025-07-03 2nd v
    [hackducky.kicad_pcb, hackducky.kicad_sch]
2025-07-24 I am done
    [bom.csv, designators.csv, hackducky.kicad_pcb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]
2025-08-09 final done with calip
    [bom.csv, designators.csv, hackducky.kicad_pcb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]
